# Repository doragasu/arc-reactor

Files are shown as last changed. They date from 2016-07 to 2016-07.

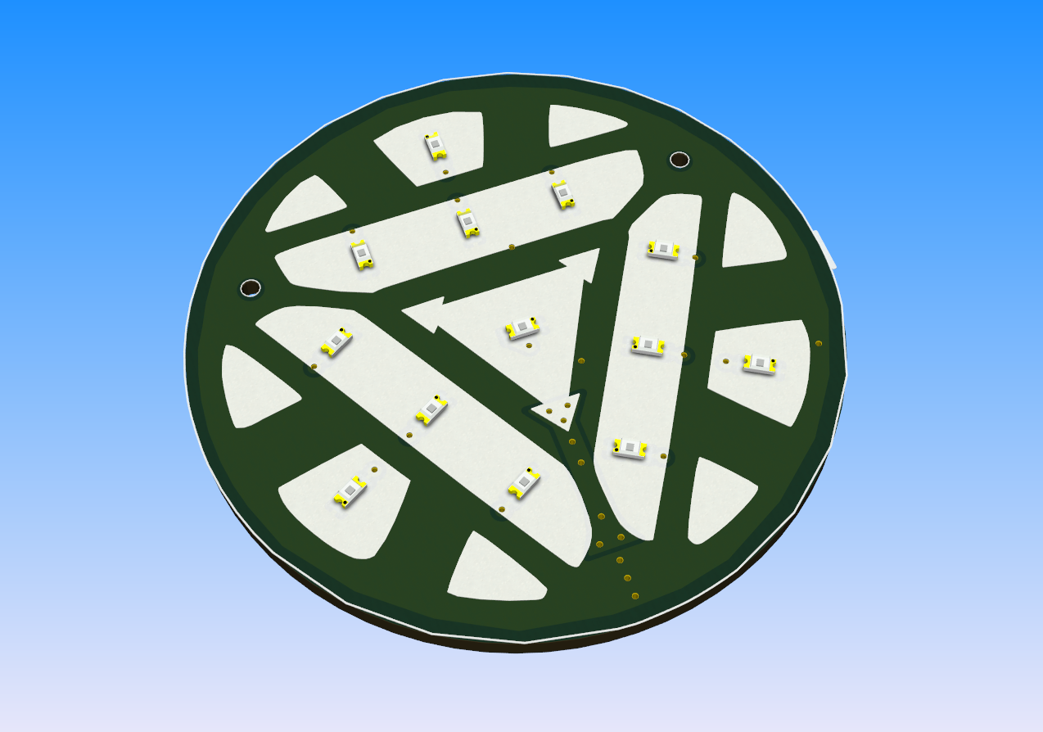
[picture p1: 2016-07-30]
sch/iron-watch.png

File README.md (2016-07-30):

# arc-reactor
Small PCB and 3D printed piece resembling one of Iron Man ARC reactor designs

# What's on this repo?
- sch directory: PCB design files (KiCAD, PDF and Gerber files).
- 3d directory: 3D printable piece (FreeCAD, SVG and STL files).
- src directory: Firmware for the ATtiny25/45/85 microcontroller, to make the LEDs slowly blink, as shown in the video: https://www.youtube.com/watch?v=LkEIsV0EnbI

# Author
All sources and CAD designs, made by doragasu.

# Status
This project is working perfect and considered finished.

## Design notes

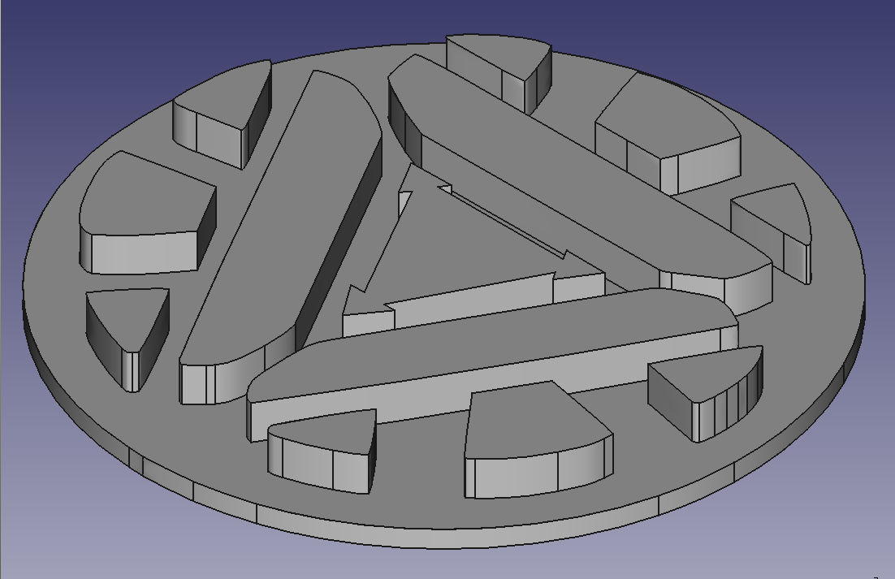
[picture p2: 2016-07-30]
3d/lpipe.png

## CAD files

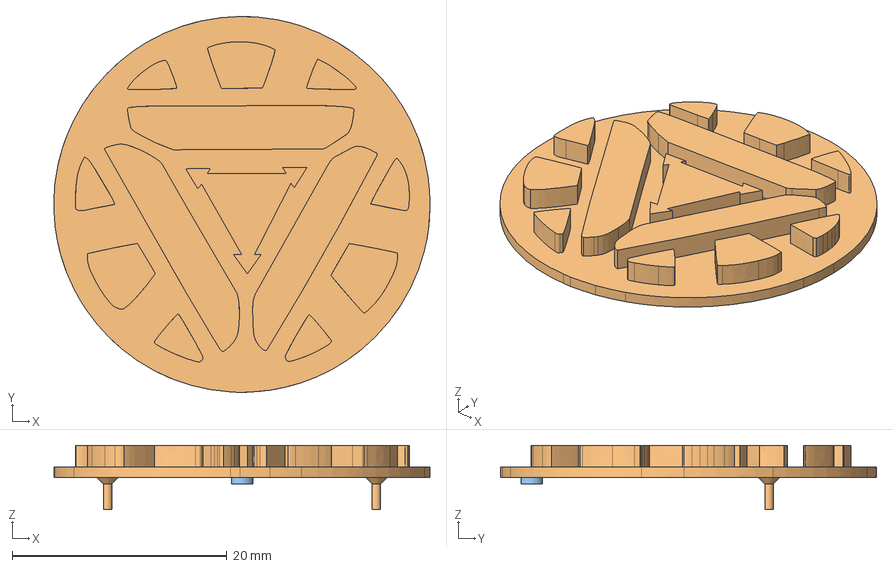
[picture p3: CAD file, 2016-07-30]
3d/lpipe.fcstd
35.0 x 35.0 x 6.00 mm
Pipe
Ch-inserts
Leg

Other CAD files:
3d/lpipe.stl

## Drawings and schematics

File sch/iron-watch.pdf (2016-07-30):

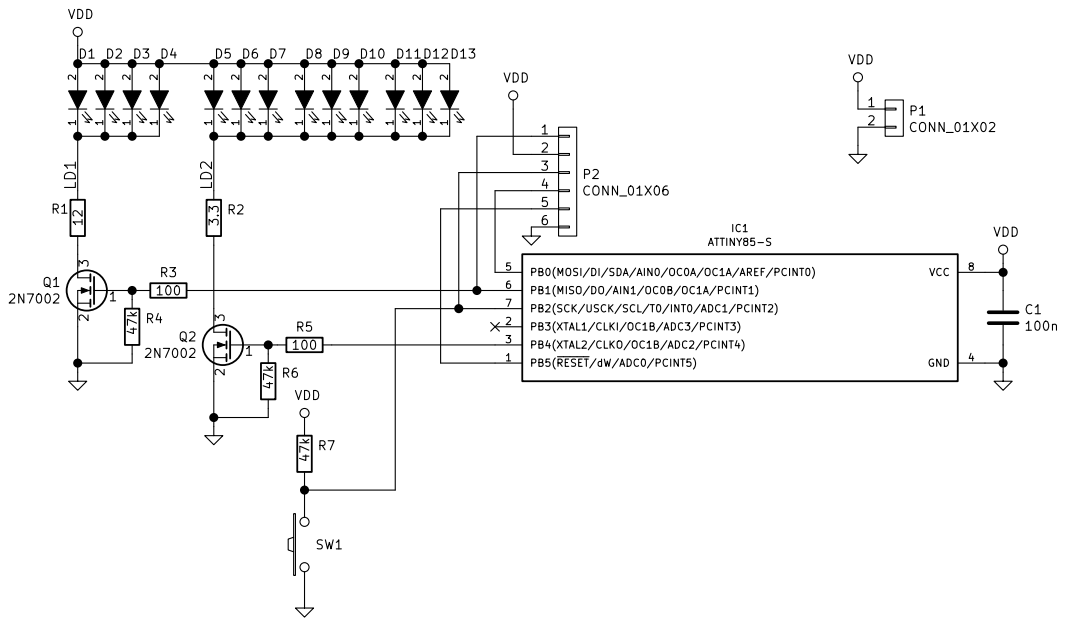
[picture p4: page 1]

License: GPLv3
File: iron-watch.sch Sheet: / doragasu

Id: 1/1 Title: IRON WATCH TAG

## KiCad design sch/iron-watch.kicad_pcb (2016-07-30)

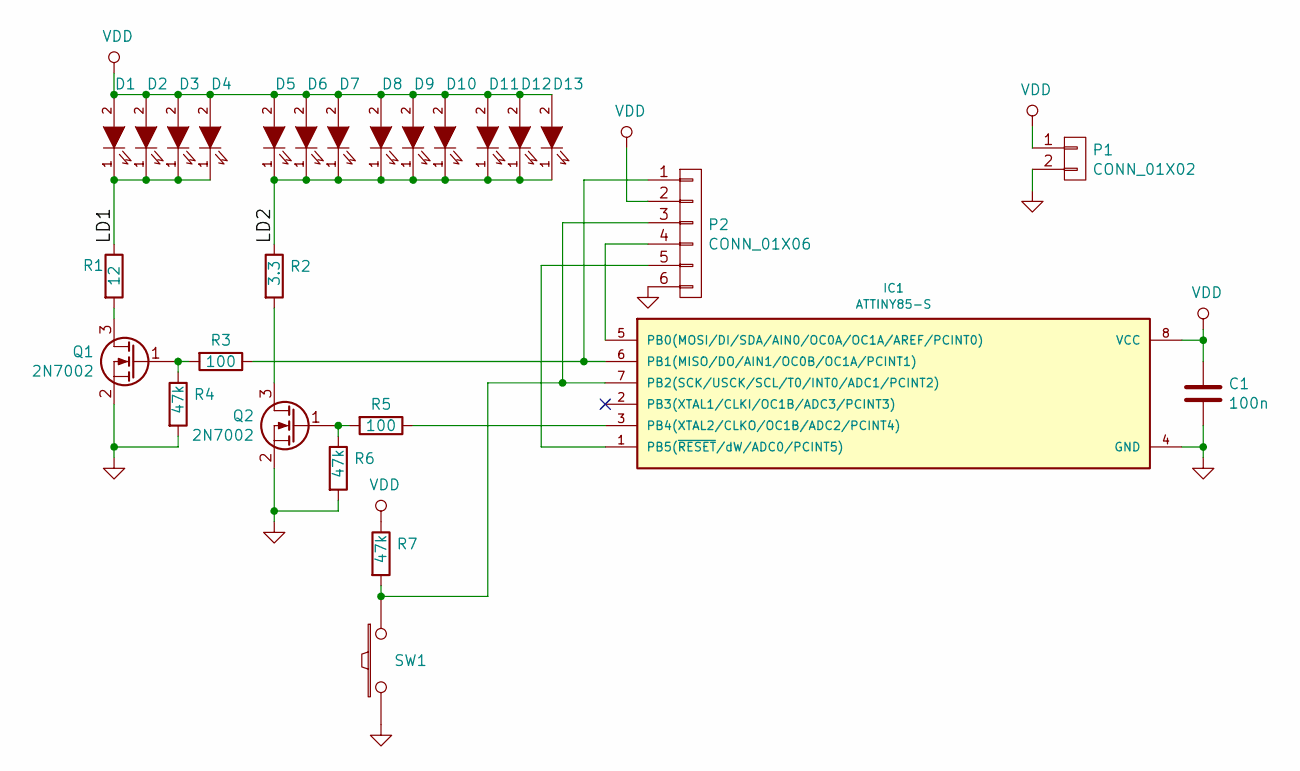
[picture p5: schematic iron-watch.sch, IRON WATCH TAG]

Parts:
C1: 100n; C_0603
D1, D2, D3, D4, D5, D6, D7, D8, D9, D10, D11, D12, D13: LED; LED-0603
IC1: ATTINY85-S; SOIC-8_3.9x4.9mm_Pitch1.27mm
P1: CONN_01X02; CR2032L_F1N_PADS
P2: CONN_01X06; CON_3x2P_2MM_SMD
Q1, Q2: 2N7002; SOT-23
R1: 12; R_0603
R2: 3.3; R_0603
R3, R5: 100; R_0603
R4, R6, R7: 47k; R_0603
SW1: SW_PUSH; C&K_KSS

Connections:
/LD1: D1.1 (K), D2.1 (K), D3.1 (K), D4.1 (K), R1.1
/LD2: D5.1 (K), D6.1 (K), D7.1 (K), D8.1 (K), D9.1 (K), D10.1 (K), D11.1 (K), D12.1 (K), D13.1 (K), R2.1
GND: C1.2, IC1.4 (GND), P1.2, P2.6, Q1.2 (S), Q2.2 (S), R4.2, R6.2, SW1.2
unnamed: IC1.1 (PB5(~RESET~/dW/ADC0/PCINT5)), P2.5
unnamed: IC1.3 (PB4(XTAL2/CLKO/OC1B/ADC2/PCINT4)), R5.1
unnamed: IC1.5 (PB0(MOSI/DI/SDA/AIN0/OC0A/OC1A/AREF/PCI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), P2.4
unnamed: IC1.6 (PB1(MISO/DO/AIN1/OC0B/OC1A/PCINT1)), P2.1, R3.1
unnamed: IC1.7 (PB2(SCK/USCK/SCL/T0/INT0/ADC1/PCINT2)), P2.3, R7.2, SW1.1
unnamed: Q1.1 (G), R3.2, R4.1
unnamed: Q1.3 (D), R1.2
unnamed: Q2.1 (G), R5.2, R6.1
unnamed: Q2.3 (D), R2.2
VDD: C1.1, D1.2 (A), D2.2 (A), D3.2 (A), D4.2 (A), D5.2 (A), D6.2 (A), D7.2 (A), D8.2 (A), D9.2 (A), D10.2 (A), D11.2 (A), D12.2 (A), D13.2 (A), IC1.8 (VCC), P1.1, P2.2, R7.1

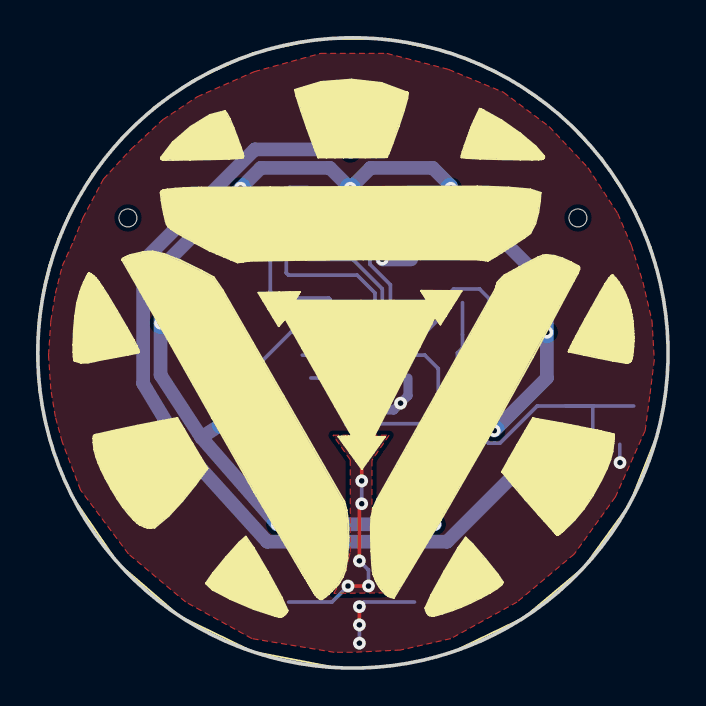
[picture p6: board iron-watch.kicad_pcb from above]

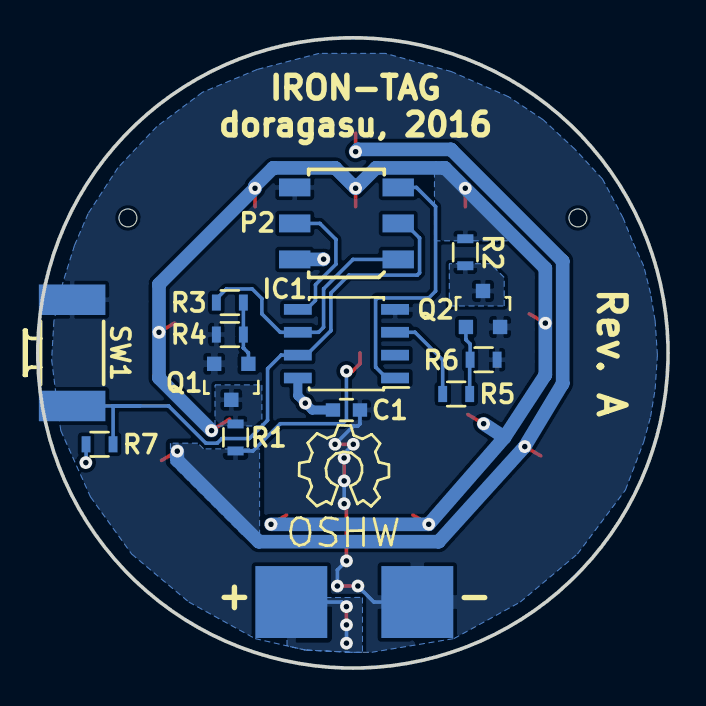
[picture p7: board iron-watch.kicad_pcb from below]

Board: 2 copper layers, 35.0 x 35.0 mm, 27 parts (14 on the bottom side), 13 nets.

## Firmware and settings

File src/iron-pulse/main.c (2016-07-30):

/************************************************************************//**
 * Generates a pulsed sequence for two LED groups, using TIMER1 PWM mode.
 * For using with IRON-TAG.
 *
 * doragasu, 2016
 ****************************************************************************/
#include <avr/signature.h>
#include <avr/interrupt.h>
#include <avr/sleep.h>
#include <avr/io.h>
#include <stdint.h>
#include <string.h>

// Fuses configuration. Uses 8MHz/8 internal clock. 128 kHz internal clock / 8
// should be enough and drain less power, but using this configuration makes
// impossible to flash the MCU via SPI unless you have a programmer that can
// use a 4 kHz or lower clock.
FUSES = {
	.low = (FUSE_CKDIV8 & FUSE_SUT0 & FUSE_CKSEL3 & FUSE_CKSEL2 & FUSE_CKSEL0),
    .high = (FUSE_SPIEN)
};

/*
 * I/O WIRING:
 * PB1 (OC1A) --> LD1 (center and external LEDs).
 * PB4 (OC1B) --> LD2 (internal LEDs).
 * SW1 --> INT0 (low level turns on LED sequence).
 */
#define LD1_PIN 		PIN1
#define LD2_PIN			PIN4
#define PUSHBUTTON_PIN	PIN2

// sin^2(x) LUT from 0 to pi/2
const uint8_t sin2_lut[] = {
	0x00, 0x00, 0x01, 0x01, 0x03, 0x04, 0x06, 0x08,
	0x0A, 0x0D, 0x10, 0x13, 0x16, 0x1A, 0x1E, 0x22,
	0x26, 0x2B, 0x30, 0x35, 0x3A, 0x40, 0x45, 0x4B,
	0x51, 0x57, 0x5D, 0x63, 0x69, 0x70, 0x76, 0x7C,
	0x83, 0x89, 0x8F, 0x96, 0x9C, 0xA2, 0xA8, 0xAE,
	0xB4, 0xBA, 0xBF, 0xC5, 0xCA, 0xCF, 0xD4, 0xD9,
	0xDD, 0xE1, 0xE5, 0xE9, 0xEC, 0xEF, 0xF2, 0xF5,
	0xF7, 0xF9, 0xFB, 0xFC, 0xFE, 0xFE, 0xFF, 0xFF
};

#define SIN2_LUT_NSAMPLES	(sizeof(sin2_lut))

// Status of the LED group
typedef enum {
	STAT_IDLE = 0,		// Idle status, LEDs OFF
	STAT_UP,			// Increasing LED brightness
	STAT_DOWN			// Decreasing LED brightness
} Status;

// Static data used to control a single LED group
typedef struct {
	volatile Status s;	// System status
	uint8_t idx;		// LUT index
	uint8_t cyc;		// Number of pending cycles
} StatData;

// Data corresponding to LD1 LEDs
static StatData ld1;
// Data corresponding to LD2 LEDs
static StatData ld2;

// PWM timer configuration, uses TIMER1 with outputs on OC1A and OC1B
// Note timer is configured to always run, it is stopped only when
// entering Power Down mode.
static inline void PwmConfig(void) {
	// OC1[AB] clear on match, set on overflow/OC1C match, /64 prescaler
	TCCR1 = (1<<PWM1A) | (1<<COM1A1) | (1<<CS12) | (1<<CS11) | (1<<CS10);
	GTCCR = (1<<PWM1B) | (1<<COM1B1);
	// Set OCR1C to max value
	OCR1C = 0xFF;
	// Enable overflow interrupt
	TIMSK = (1<<TOIE1);
}

// System initialization: static data, I/O and interrupts.
static inline void SysInit(void) {
	// Static data initialization
	memset((void*)&ld1, 0, sizeof(ld1));
	memset((void*)&ld2, 0, sizeof(ld2));
	// Disable clock for all peripherals excepting TIMER1 to save power.
	PRR = (1<<PRADC) | (1<<PRUSI) | (1<<PRTIM0);
	// Set Sleep Mode to Power Down
	set_sleep_mode(SLEEP_MODE_PWR_DOWN);
	// Configure PWM outputs
	DDRB = (1<<LD1_PIN) | (1<<LD2_PIN);
	// Turn off LEDs, enable pushbutton pin pull-up
	PORTB = (1<<PUSHBUTTON_PIN);
	// Configure TIMER1 for PWM operation
	PwmConfig();
}

static inline void SysPowerDown(void) {
	cli();					// Disable interrupts for atomic execution
	sleep_enable();			// Enable SLEEP instruction
	// Ensure LEDs are OFF
	PORTB &= ~((1<<LD1_PIN) | (1<<LD2_PIN));
	GIMSK = (1<<INT0);		// Enable pushbutton interrupt
	// WARNING: BOD disable is only implemented for ATtiny85 devices
	// revision C and newer
	sleep_bod_disable();	// Disable BOD during sleep
	sei();					// Enable global interrupts
	sleep_cpu();			// Go to sleep mode
	sleep_disable();		// Disable SLEEP instruction
}

// Configures LEDs to start the blinking sequence
static inline void SysLedBlinkStart(void) {
	// Just set indexes, cycles  and status. Interrupts will do the hard work
	ld1.cyc = 8;
	ld2.cyc = 4;
	ld1.idx = ld2.idx = 0;
	ld1.s = ld2.s = STAT_UP;
}

// Test if any of the LEDs are blinking
#define LedsBlinking()	(ld1.s || ld2.s)

// Main program
int main(void) {
	// Configure system
	SysInit();

	// Main loop, one iteration per complete LED sequence.
	while (1) {
		// Power down until button pressed
		SysPowerDown();
		// Pushbutton interrupt has awakened the system here
		set_sleep_mode(SLEEP_MODE_IDLE);
		// Start LEDs blinking sequence
		SysLedBlinkStart();
		// Enter IDLE state while LEDs blinking
		while (LedsBlinking()) sleep_cpu();
		set_sleep_mode(SLEEP_MODE_PWR_DOWN);
	}
	return 0;
}

// Pushbutton interrupt, used to wake from sleep mode.
ISR(INT0_vect) {
	// Disable pushbutton interrupt to prevent the CPU from being locked if
	// user keeps the button pressed
	GIMSK &= ~(1<<INT0);
}

// Timer overflow interrupt, update PWM values depending on LED group status.
ISR(TIMER1_OVF_vect) {
	// NOTE: These values will not be effective until next overflow occurs.
	// Update OCR1A for LED group 1.
	switch (ld1.s) {
		case STAT_IDLE:
			break;

		case STAT_UP:
			OCR1A = sin2_lut[ld1.idx++];
			if (SIN2_LUT_NSAMPLES == ld1.idx) {
				ld1.s = STAT_DOWN;
			}
			break;

		case STAT_DOWN:
			OCR1A = sin2_lut[--ld1.idx];
			if (0 == ld1.idx) {
				ld1.s = --ld1.cyc?STAT_UP:STAT_IDLE;
			}
			break;
	}

	// Update OCR1B for LED group 2
	switch (ld2.s) {
		case STAT_IDLE:
			break;

		case STAT_UP:
			OCR1B = sin2_lut[ld2.idx++>>1];
			if ((SIN2_LUT_NSAMPLES<<1) == ld2.idx) {
				ld2.s = STAT_DOWN;
			}
			break;

		case STAT_DOWN:
			OCR1B = sin2_lut[--ld2.idx>>1];
			if (0 == ld2.idx) {
				ld2.s = --ld2.cyc?STAT_UP:STAT_IDLE;
			}
			break;
	}
}
